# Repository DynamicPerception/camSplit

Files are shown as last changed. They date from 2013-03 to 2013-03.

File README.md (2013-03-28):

camSplit Board
==============

The camSplit board is the heart of the [MUX-4 4-Way Isolated Camera Splitter](http://dynamicperception.com/products/mux-4-camera-splitter) sold by Dynamic Perception LLC.

Not limited to controlling cameras, the camSplit provides a safe, and isolated way to multiply any two trigger outputs out to four separate devices, even if those devices have wildly different voltages (from 1.5V to 80V DC).  True optical isolation on every port means that different devices can safely react to the same control signal - allowing you to synchronize lights, cameras, and more.

Key Features 
------------

- Complete optical isolation between all cameras and control inputs 
- Can work with isolated intervalometer outputs (like the MX2) 
- Runs on 2x AAA batteries, will last many months between changes 
- Manual triggering of the shutter/focus lines via pushbuttons 
- Can be daisy-chained (feed one output to the input of another) 

License and Copyright
---------------------

camSplit and the MUX-4 are Copyright (c) 2012-2013 Dynamic Perception LLC.

All files shared under the Creative Commons Attibution-Share-Alike 3.0 License.

camSplit and MUX-4 names are trademarks of Dynamic Perception LLC.

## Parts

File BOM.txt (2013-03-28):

Partlist

Exported from camSplit.sch at 3/28/13 10:39 AM

EAGLE Version 6.1.0 Copyright (c) 1988-2012 CadSoft

Assembly variant: 

Part     Value                       Device                      Package    Library               Sheet

2XAAA                                12BH423-GR                  12BH423-GR eagle-plastic-devices 1
CAM1     161-2508-EXTHRU-HOLE-PCB-RA 161-2508-EXTHRU-HOLE-PCB-RA PCB-HORIZ  kobiconn-161-2508-ex  1
CAM2     161-2508-EXTHRU-HOLE-PCB-RA 161-2508-EXTHRU-HOLE-PCB-RA PCB-HORIZ  kobiconn-161-2508-ex  1
CAM3     161-2508-EXTHRU-HOLE-PCB-RA 161-2508-EXTHRU-HOLE-PCB-RA PCB-HORIZ  kobiconn-161-2508-ex  1
CAM4     161-2508-EXTHRU-HOLE-PCB-RA 161-2508-EXTHRU-HOLE-PCB-RA PCB-HORIZ  kobiconn-161-2508-ex  1
CAM_IN   161-2508-EXTHRU-HOLE-PCB-RA 161-2508-EXTHRU-HOLE-PCB-RA PCB-HORIZ  kobiconn-161-2508-ex  1
FOC      SKHHCWA010                  SKHH                        SKHH       alps                  1
JP1      conn                        PINHD-1X6                   1X06       pinhead               1
LFOC                                 LED3MM                      LED3MM     SparkFun              1
LSHT                                 LED3MM                      LED3MM     SparkFun              1
OK1      ACPL-227                    ACPL-227                    SOIC8      avago-opto            1
OK2      ACPL-227                    ACPL-227                    SOIC8      avago-opto            1
OK3      ACPL-227                    ACPL-227                    SOIC8      avago-opto            1
OK4      ACPL-227                    ACPL-227                    SOIC8      avago-opto            1
R1       90                          R-US_R0402                  R0402      resistor              1
R2       90                          R-US_R0402                  R0402      resistor              1
R3       90                          R-US_R0402                  R0402      resistor              1
R4       90                          R-US_R0402                  R0402      resistor              1
R5       90                          R-US_R0402                  R0402      resistor              1
R6       90                          R-US_R0402                  R0402      resistor              1
R7       90                          R-US_R0402                  R0402      resistor              1
R8       90                          R-US_R0402                  R0402      resistor              1
R9       150k                        R-US_R0402                  R0402      resistor              1
R10      150k                        R-US_R0402                  R0402      resistor              1
R11      90                          R-US_R0402                  R0402      resistor              1
R12      90                          R-US_R0402                  R0402      resistor              1
SHT      SKHHCWA010                  SKHH                        SKHH       alps                  1

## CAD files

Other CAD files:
SketchUp/cam-split.skp

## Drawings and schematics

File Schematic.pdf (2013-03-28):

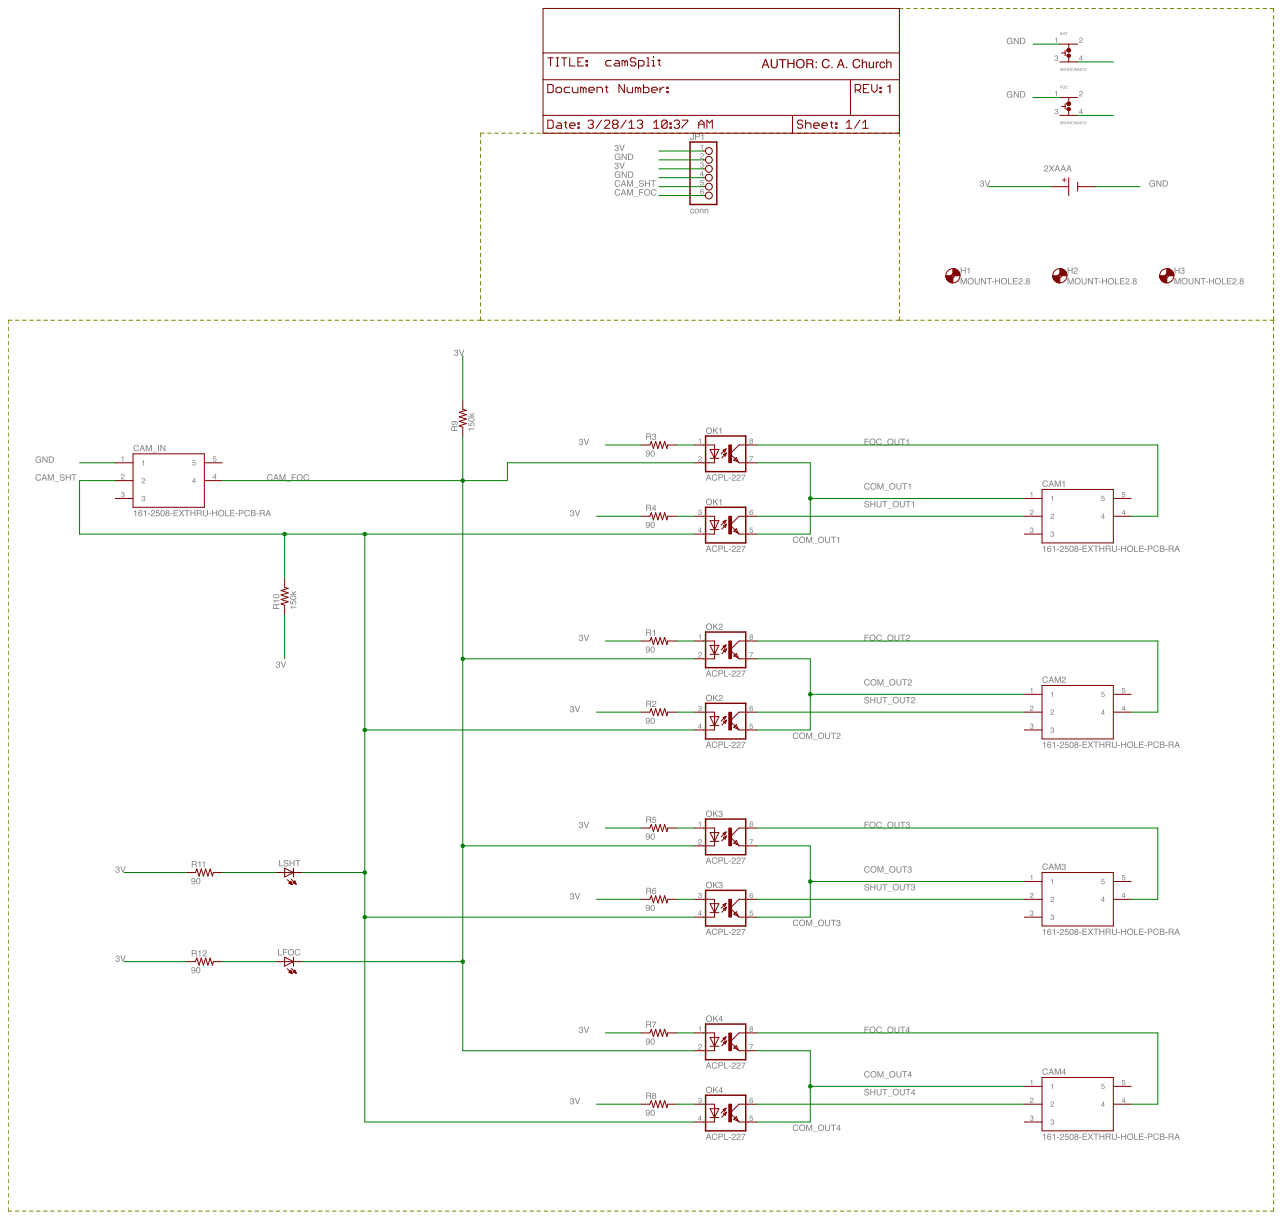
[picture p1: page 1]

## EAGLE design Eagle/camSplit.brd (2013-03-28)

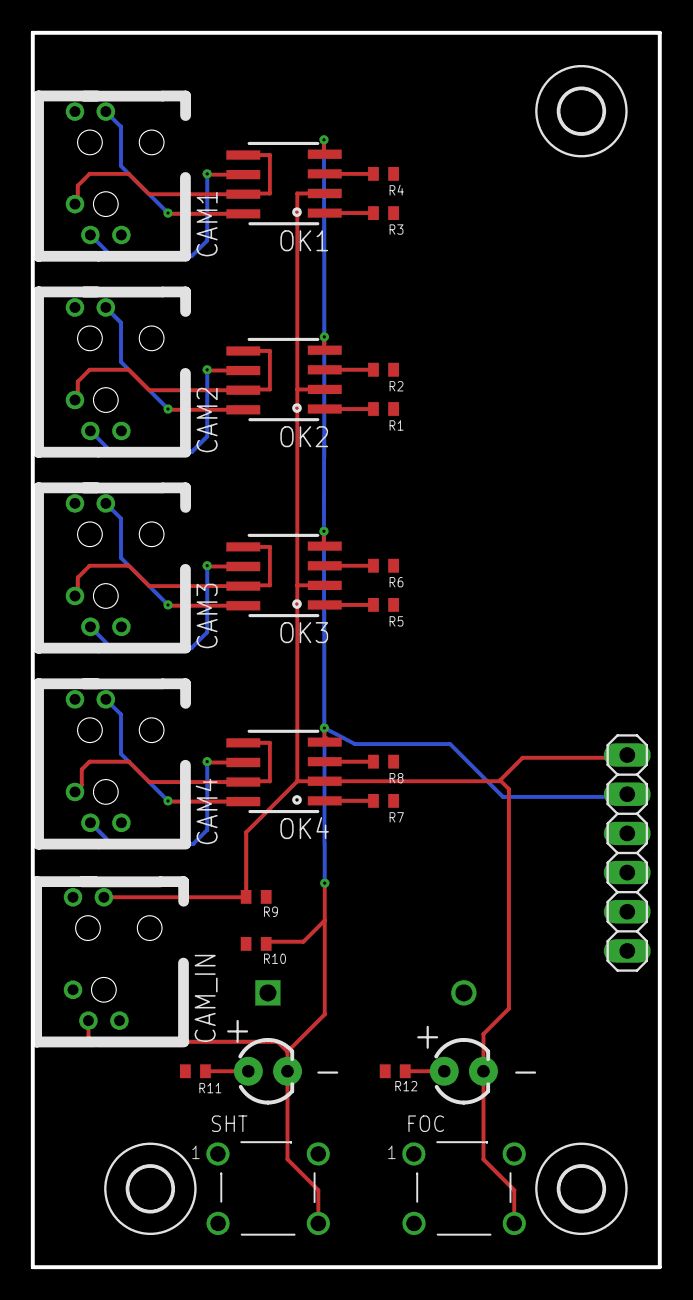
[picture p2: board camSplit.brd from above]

Board: 2 copper layers, 40.6 x 80.0 mm, 30 parts (1 on the bottom side), 26 nets.

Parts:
2XAAA: 12BH423-GR
CAM1, CAM2, CAM3, CAM4: 161-2508-EXTHRU-HOLE-PCB-RA; PCB-HORIZ
CAM_IN: 161-2508-EXTHRU-HOLE-PCB-RA; PCB-HORIZ
FOC: SKHHCWA010; SKHH
H1, H2, H3: MOUNT-HOLE2.8; 2,8
JP1: conn; 1X06
LFOC: LED3MM
LSHT: LED3MM
OK1, OK2, OK3, OK4: ACPL-227; SOIC8
R1, R2, R3, R4, R5, R6, R7, R8, R11, R12: 90; R0402
R9, R10: 150k; R0402
SHT: SKHHCWA010; SKHH

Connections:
3V: 2XAAA.POS, JP1.1, JP1.3, R1.1, R2.1, R3.1, R4.1, R5.1, R6.1, R7.1, R8.1, R9.2, R10.1, R11.1, R12.1
CAM_FOC: CAM_IN.4, FOC.4, JP1.6, LFOC.K, OK1.2, OK2.2, OK3.2, OK4.2, R9.1
CAM_SHT: CAM_IN.2, JP1.5, LSHT.K, OK1.4, OK2.4, OK3.4, OK4.4, R10.2, SHT.4
COM_OUT1: CAM1.1, OK1.5, OK1.7
COM_OUT2: CAM2.1, OK2.5, OK2.7
COM_OUT3: CAM3.1, OK3.5, OK3.7
COM_OUT4: CAM4.1, OK4.5, OK4.7
FOC_OUT1: CAM1.4, OK1.8
FOC_OUT2: CAM2.4, OK2.8
FOC_OUT3: CAM3.4, OK3.8
FOC_OUT4: CAM4.4, OK4.8
GND: 2XAAA.NEG, CAM_IN.1, FOC.1, JP1.2, JP1.4, SHT.1
unnamed: OK1.1, R3.2
unnamed: OK2.1, R1.2
unnamed: OK1.3, R4.2
unnamed: OK2.3, R2.2
unnamed: OK3.1, R5.2
unnamed: OK3.3, R6.2
unnamed: OK4.1, R7.2
unnamed: OK4.3, R8.2
unnamed: LSHT.A, R11.2
unnamed: LFOC.A, R12.2
SHUT_OUT1: CAM1.2, OK1.6
SHUT_OUT2: CAM2.2, OK2.6
SHUT_OUT3: CAM3.2, OK3.6
SHUT_OUT4: CAM4.2, OK4.6
